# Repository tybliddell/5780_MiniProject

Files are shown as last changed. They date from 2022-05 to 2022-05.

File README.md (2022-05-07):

# ꟼ̷̢̛̭̪̞̑̈́̚Ĩ̴̺͕̞̟́̎͛X̴̨̳̯͖́̈́̉͠Y̷̛̰̲̲̯͆̈́̓Ɔ̷̬̟̲̆̒̄̚ͅA̴̼̻͉̼͋́̿͗M̸͎̘̲̗̊́͘͠ ̶͓̼̜̱̀̔͋͘-̵̡̭̰͓̑̎͐̉ ̶̯͉̟̄̒̀̕͜ꓭ̷͙̦͎̣͑̓̚͝O̷̺̟̪̠̎̋̅͝T̸̳͈͕͖̎̃̅͝

## Explanation

The Pixycam-Bot is a ping pong ball tracking robot that contains a camera that sits on a pan and tilt-controllable assembly to continuously point itself at the ball. The project itself does little more than entertain us, but it could easily be expanded into many different applications including an automatic referee, an auto face-tracking webcam, and more.

## Diagram for project
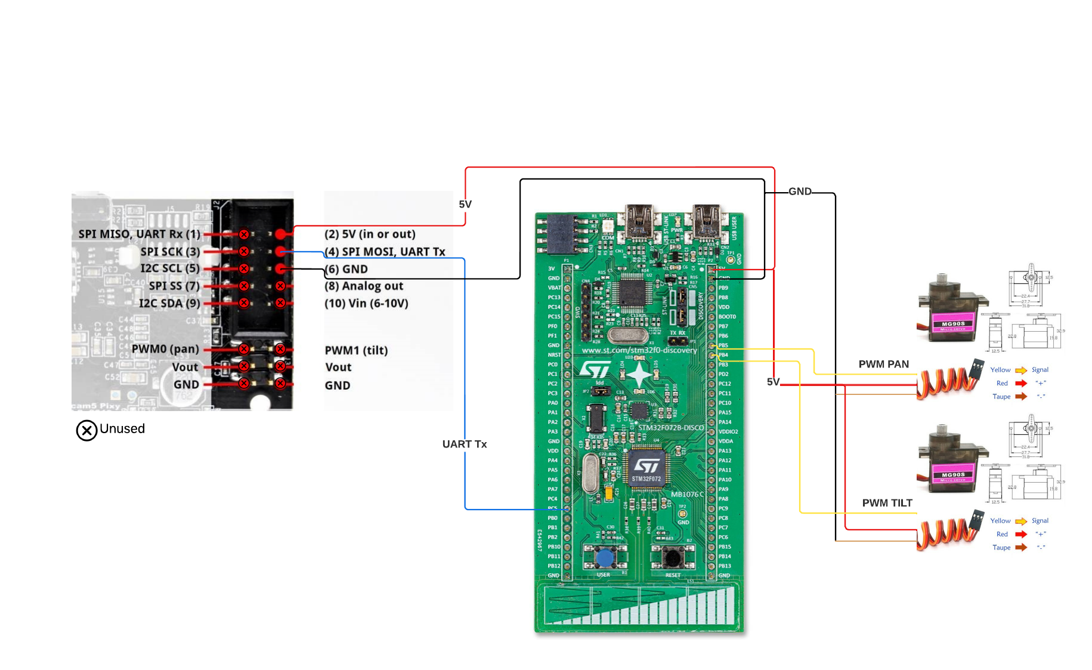
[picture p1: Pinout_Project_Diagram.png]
Pixy Diagram


## Pixy Settings Considerations

We seemed to have a decent amount of success using 115200 for the baud rate of the camera. This is easy to set using the PixyMon software you can obtain at the pixy website [here](https://pixycam.com/downloads-pixy1/). The specifics on how to navigate the software and change these settings can be located on the wiki page [here](https://docs.pixycam.com/wiki/doku.php?id=wiki:v1:porting_guide). 

### Lighting settings

The Pixycam has a lot of settings it holds internally and they can be modified/stored in the memory. There are a few bars that each make some changes to the way the hardware interprets and processes the video stream. Here are the settings for that tuning:

Within the signature tuning tab, you can find the following:
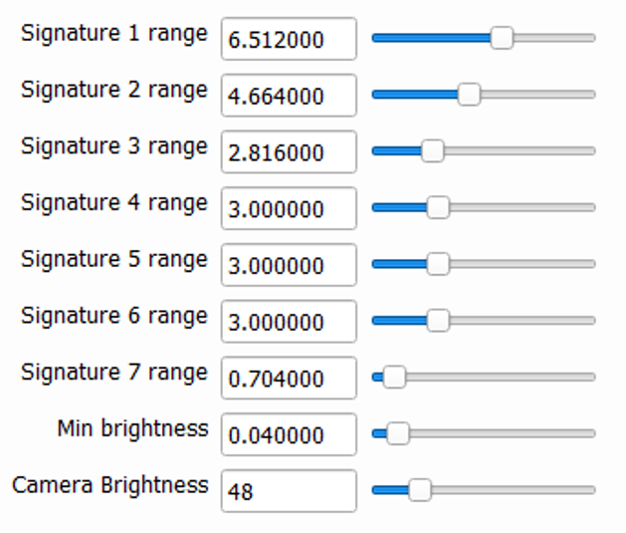
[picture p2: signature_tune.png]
Signature Tuining params


These parameters seem to have different uses for the preprocessing, but have a direct relationship to the amount of post processing that can be done. I was unable to label these with anything useful, so we just sort of played around with the values until we found something that worked well in the lab. Note* This kind of development was mostly due to time, but we quickly realized that the pixy is a camera that can't really be used in a dynamic environment all too well. Using a better camera sensor with beefier post processing techniques would allow for harder, better, faster, and stronger tracking feedback. 

### Capture settings

To capture a single item in frame, we needed to make some mods to the blocks tab. These changes are shown below:

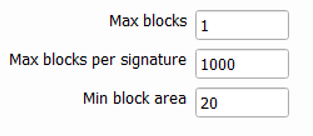
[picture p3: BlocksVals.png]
Changes for Blocks settings


The changes here allow you to capture a specified size, number of captures, and max number of blocks per image captured. Since the ball we were planning to use could be fairly small when farther away, we wanted to make sure the size was still picked up. The 20 min seemed like a decent choice for that value, but we saw some issues with picking up stray signatures around the ball or from reflections in the area. More testing needed to find out what the best way to minimize that would be. 

### Misc settings

The next thing is the baud rate for the UART, and the expert settings are last pieces needed to be configured. Uart settings as well as I2C settings can be seen below and found in the Interface tab, and the Expert tab contains some settings for ...uuhhh experts :) . 

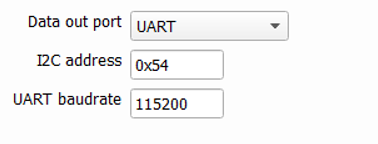
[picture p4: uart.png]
Interface for baud rate


#### Expert stuff

The expert settings are shown below and mostly stay as they are. The LED brightness and the Teaching Threshold are the only ones you likely want to mess with unless you know what you are doing with the others. 

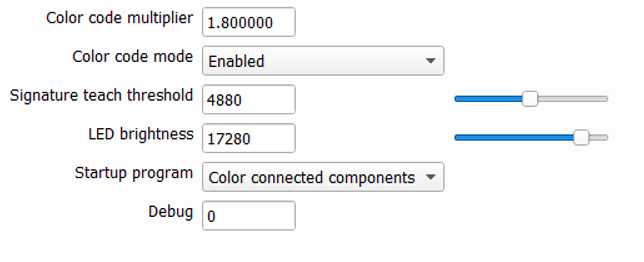
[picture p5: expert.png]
Expert Settings


#### 5780 Mini Project Authors
Tyler Liddell [owns the repo](https://github.com/tybliddell)

Miguel Gomez [Github Page](https://github.com/Mgomez-01)

Rich Baird 😎 [Github Page](https://github.com/richbai90)

Hyrum Saunders [Github Page](https://github.com/hyrum-saunders)

### Project Demonstration and Milestone Explanation
[Watch our demonstration here!](https://youtu.be/rSYqTkc3UDk)

# Thanks for stopping by!

We at the Pixycam-Bot team would like to thank you for making it to the bottom of the readme and going through out stuff! We are glad you could take a moment to rummage through our page to see what we made! As a thank you, we would love for you to take a second to watch this sincere video of us expressing our appreciation.[Enjoy](https://bit.ly/3yhirYQ)

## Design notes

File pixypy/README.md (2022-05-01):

# Pixypy

## A simple pixy emulator written in python

* Communicates over UART
* Simulate motion in x/y plane
* Use different easing functions to simulate realistic motion detection

## TODO

* Document usage
* GUI

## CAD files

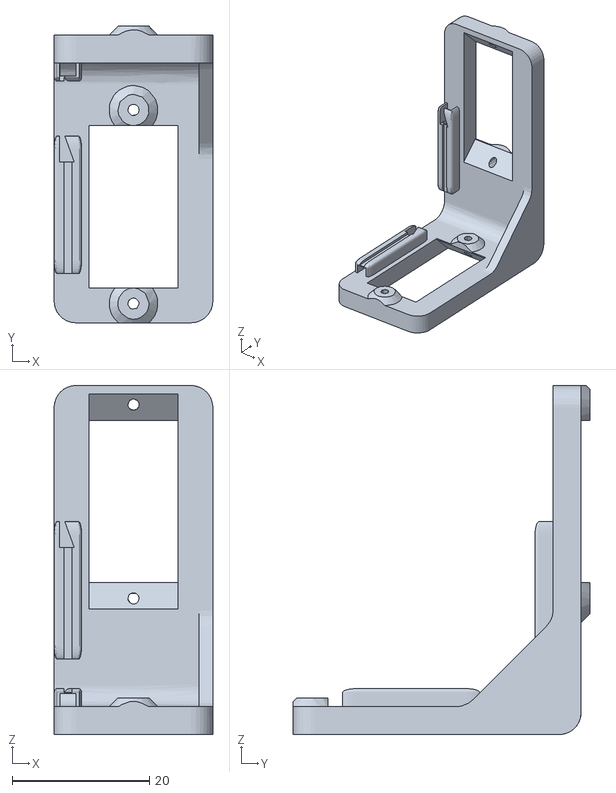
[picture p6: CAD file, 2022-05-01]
print_files/Pan_Tilt_Bracket_V7.stl
23.1 x 43.2 x 50.8

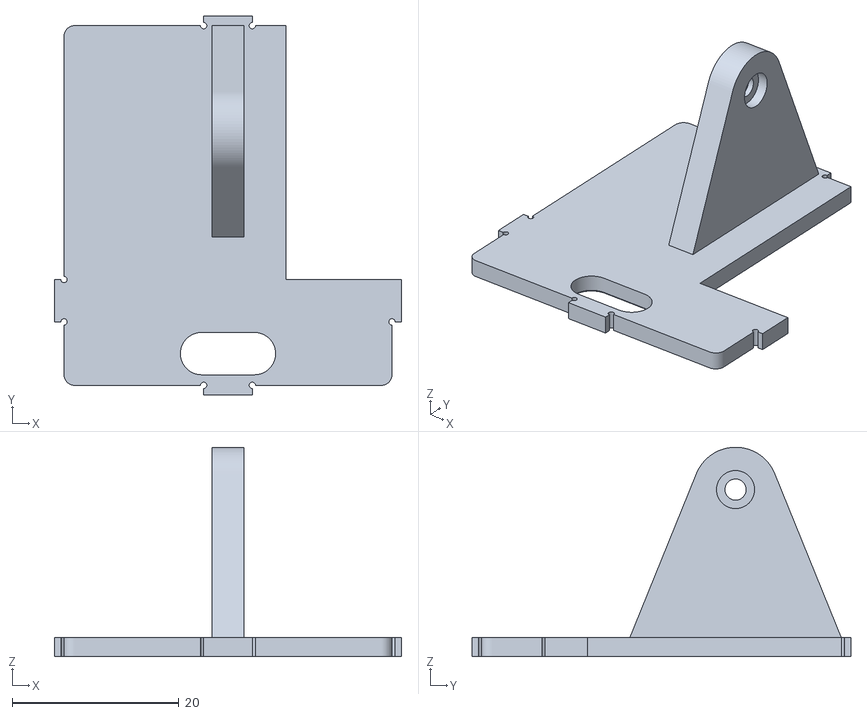
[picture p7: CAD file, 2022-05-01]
print_files/Back_Cover_initial.stl
41.7 x 45.5 x 25.1

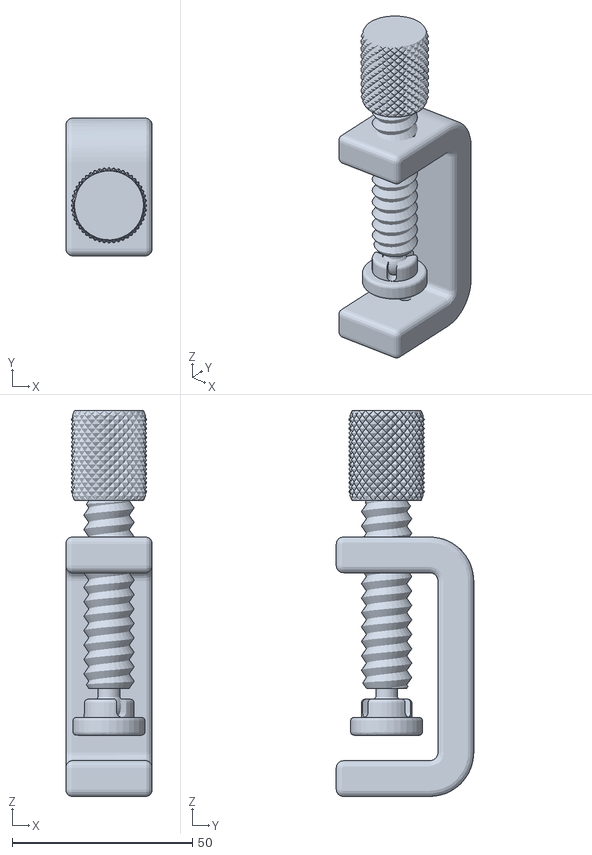
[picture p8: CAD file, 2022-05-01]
print_files/Clamp_Base_V3.stl
23.9 x 38.1 x 107.0

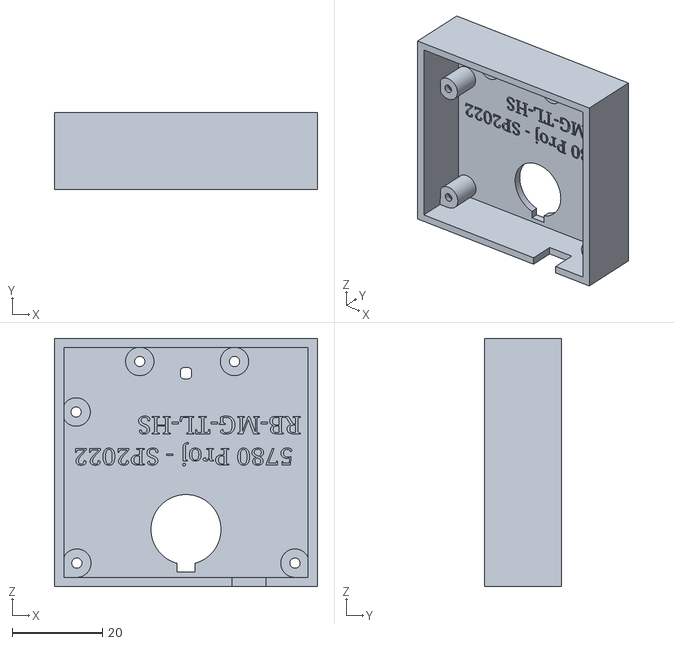
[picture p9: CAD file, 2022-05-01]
print_files/PixyCam_Cover_V22.stl
58.3 x 17.0 x 55.0

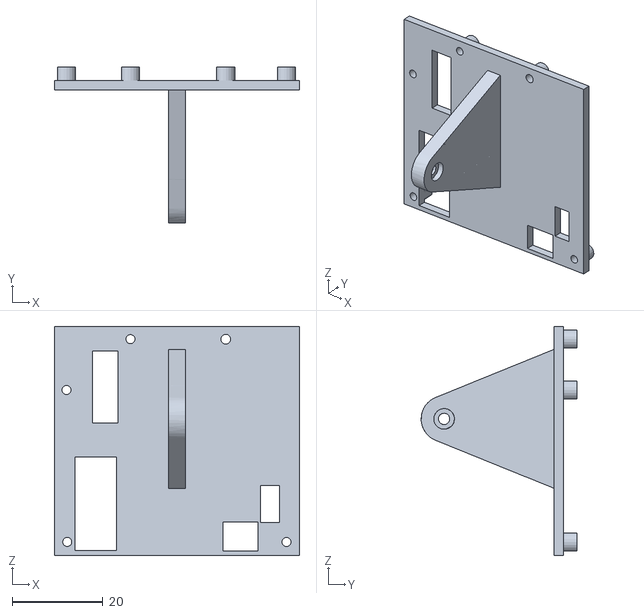
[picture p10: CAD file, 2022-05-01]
print_files/PixyCam_Back_Cover_V20.stl
54.0 x 34.3 x 50.5

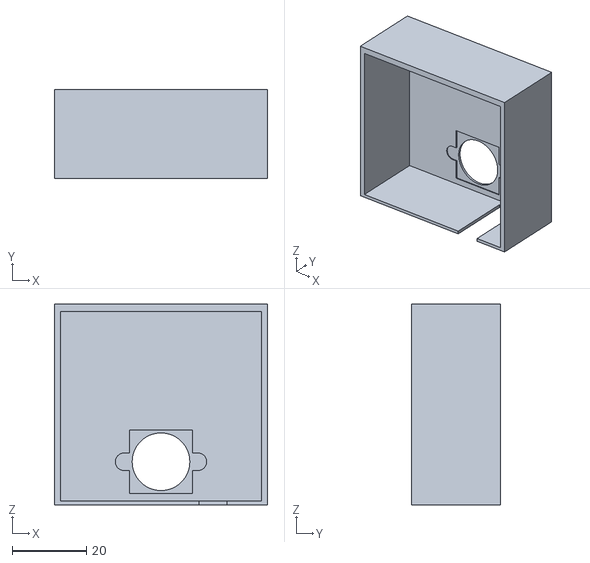
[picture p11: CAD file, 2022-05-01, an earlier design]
print_files/PixyCam_Cover_V4.stl
57.3 x 24.0 x 54.0

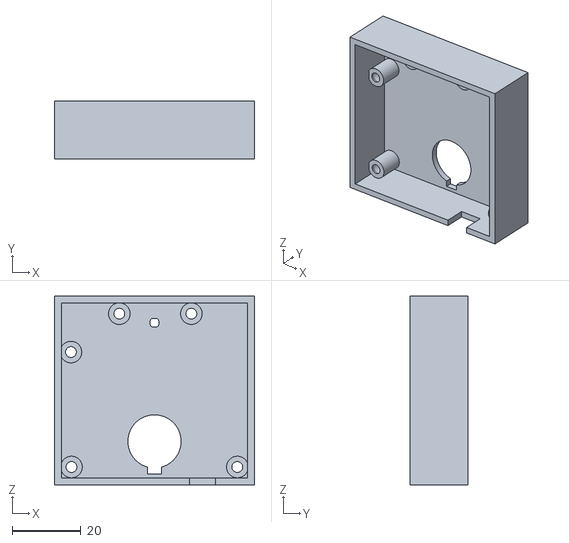
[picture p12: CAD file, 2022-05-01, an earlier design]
print_files/PixyCam_Cover_V11.stl
58.3 x 17.0 x 55.0

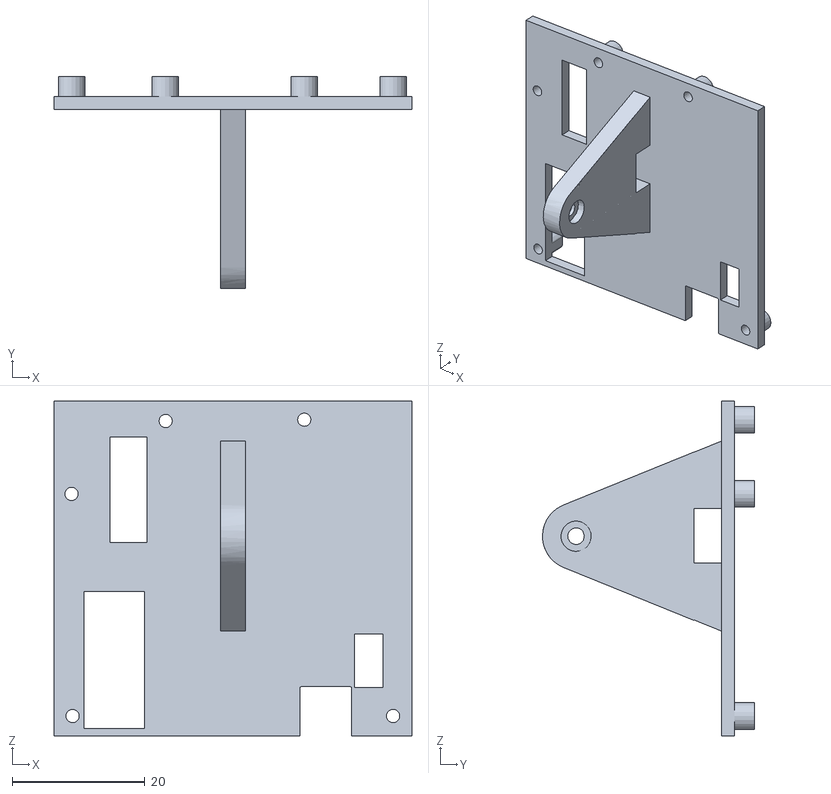
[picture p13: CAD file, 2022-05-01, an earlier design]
print_files/PixyCam_Back_Cover_V9.stl
54.0 x 32.0 x 50.5

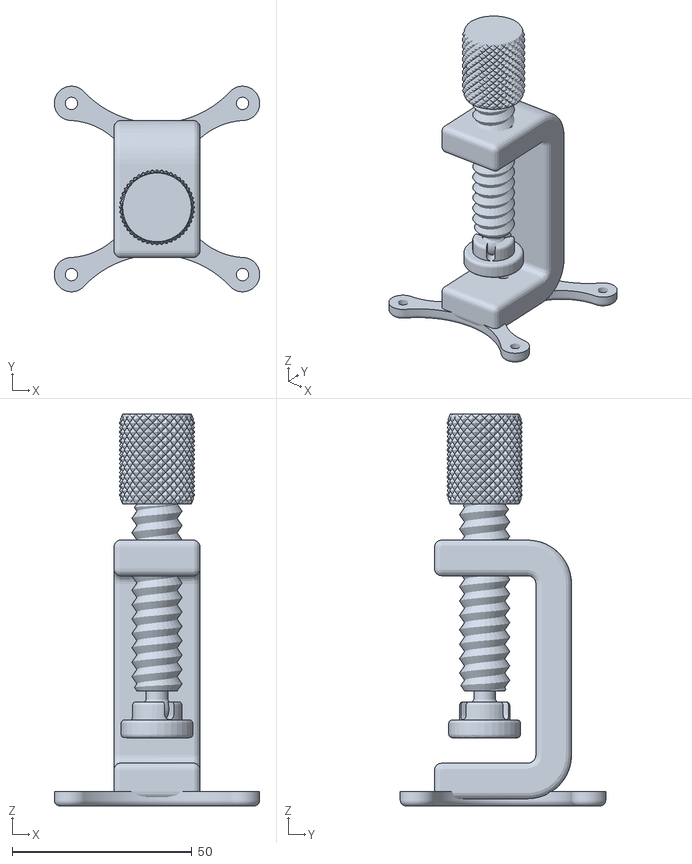
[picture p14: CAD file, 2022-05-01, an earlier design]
print_files/Clamp_Base_V1.stl
57.1 x 57.2 x 109.0

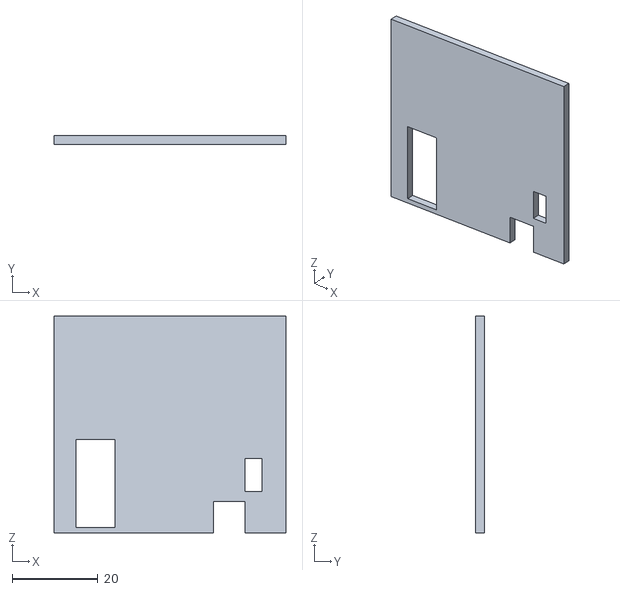
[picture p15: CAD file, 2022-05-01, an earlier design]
print_files/PixyCam_Back_Cover_V1.stl
54.0 x 2.00 x 50.5

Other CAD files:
print_files/Clamp_Base_Final.stl
print_files/gcode_tests/Clamp_diff_vals_screw.3mf
print_files/Pan_Tilt_Bracket_V2.stl
print_files/PixyCam_Cover_V1.stl
print_files/PixyCam_Back_Cover_V10.stl
print_files/PixyCam_Cover_V14.stl
print_files/Pan_Tilt_Bracket_V1.stl
print_files/Pan_Tilt_Bracket_V3.stl
print_files/Pan_Tilt_Bracket_V4.stl
print_files/Pan_Tilt_Bracket_V5.stl
print_files/Pan_Tilt_Bracket_V6.stl
print_files/PixyCam_Back_Cover_V15.stl
print_files/PixyCam_Back_Cover_V2.stl
print_files/PixyCam_Back_Cover_V3.stl
print_files/PixyCam_Back_Cover_V8.stl
print_files/PixyCam_Cover_V15.stl
print_files/PixyCam_Cover_V16.stl
print_files/PixyCam_Cover_V17.stl
print_files/PixyCam_Cover_V18.stl
print_files/PixyCam_Cover_V2.stl

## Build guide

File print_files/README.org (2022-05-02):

* Complete set of printing files needed for the build

** some prints were remixed from parts on Thingiverse.
- pieces remixed were obtained at the following
  [[https://www.thingiverse.com/thing:3180802][Pixy2Stuff]]

Parts did not fit the original PixyCam and the need for modifications arose. All modifications and custom parts made were designed and printed by Miguel Gomez with and Ender 3 3D printer at home. 

** Highlights for the project building process

The total amount of time spent designing, modifying, updating, and revising the 3D prints is not something that was a reqirement for the project, nor was it something that would receive any credit in the project in particular, but I still wanted to update this page to give an overview of the process in case someone would like to take this project and make their own changes/revisions.

In total, there were, on average, 15 different versions of each file that was included in the project that each needed its own care and attention.

*** Housing
The housing of the device in particular had the most amount of revisions as it needed a good fit for the camera, easy outside access to the lens housing of the camera, while also protecting the components on the inside and allowing us to plug in from the rear. The housing was really a single model that I decided to separate into two parts. The rear cover and the shell.

**** shell
The shell needed design changes to allow the camera button on the top to be accessible for reprogramming of the color for tracking, as well as a hold for the lens and the LED that indicated whether or not something was located. These modifications were completed by myself (Miguel Gomez) as I took measurements of the board and created a custom model in fusion 360 that I used as the starting point.

From there, revisions to the model were made as I dialed in the printer settings necessary to minimize squish at the floor, shrinkage of the part as it cooled, and modified the amount of infill for the rigidity/structure of the housing. Part of that process is shown in the included images directory and the stl files that are seen above.  

**** rear cover
The rear cover was a bit trickier. In addition to the squish at the floor and shrinkage of the part as it cools, it required a change in orientation for the print after adding in the pieces for the screws to attach to. These changes allowed for the screws to make good contact with the rear cover through the housing holes, and allow for a good adhesion of the mounting arm for the servo motor. The design was modified to shift the arm further back after it was found to interfere with the mobility of the tilting given the connected wires on the back of the camera. Adding in the extra space allowed for a fluid movement that did not cause any pinching in the wires, minimizing the stresses on the wires over time as the assembly moved around.

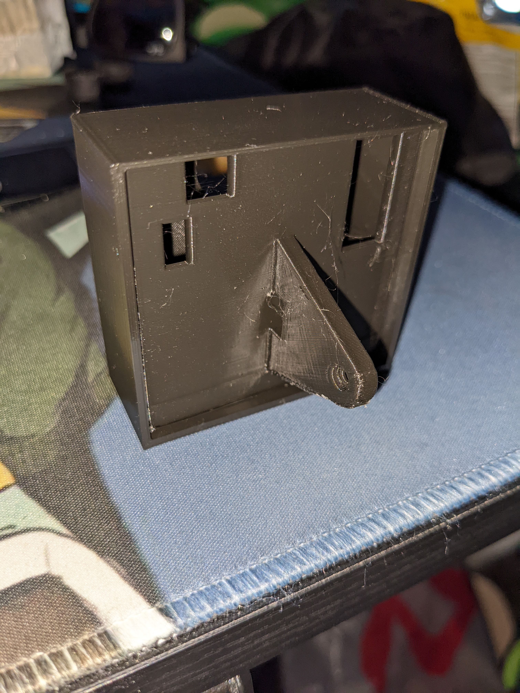
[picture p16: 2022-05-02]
print_files/images/Housing_and_cover.jpg

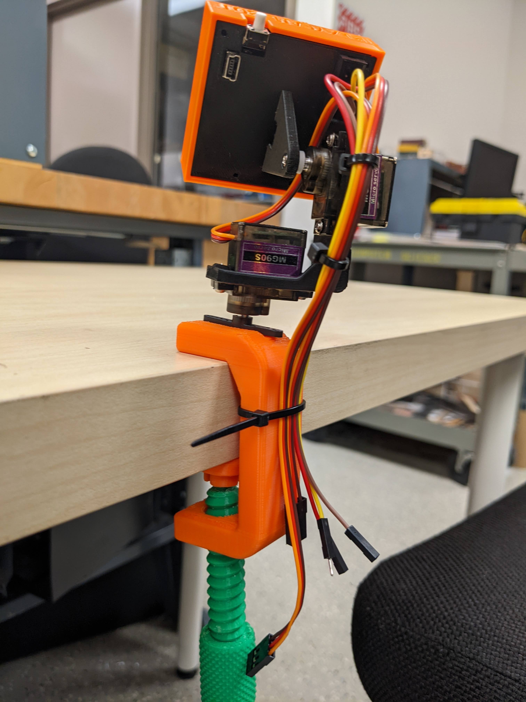
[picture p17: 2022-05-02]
print_files/images/cables_management.jpg

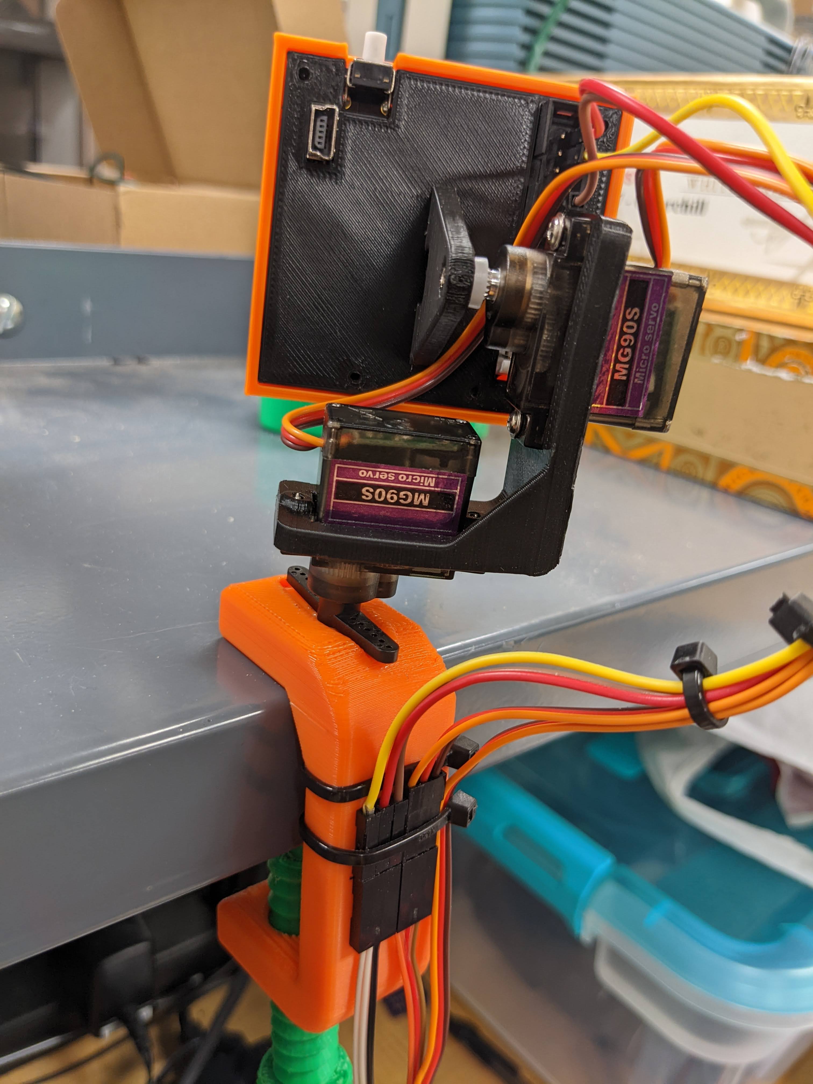
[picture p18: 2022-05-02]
print_files/images/Complete_cables_tied.jpg

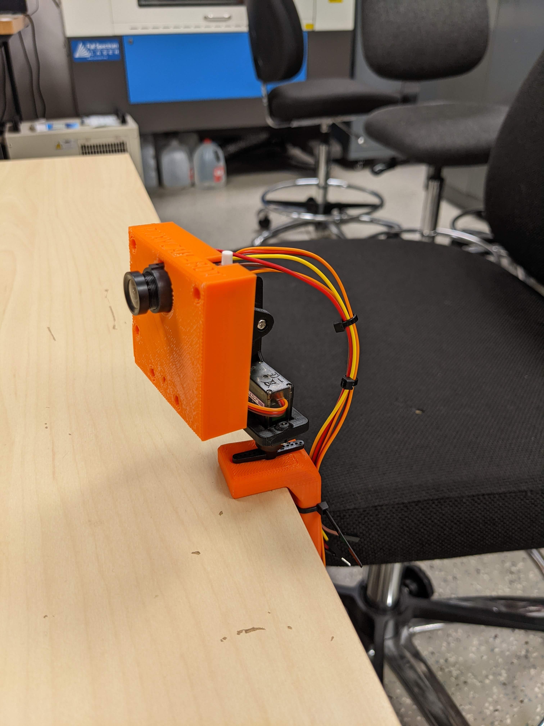
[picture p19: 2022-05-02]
print_files/images/Nearly_complete.jpg

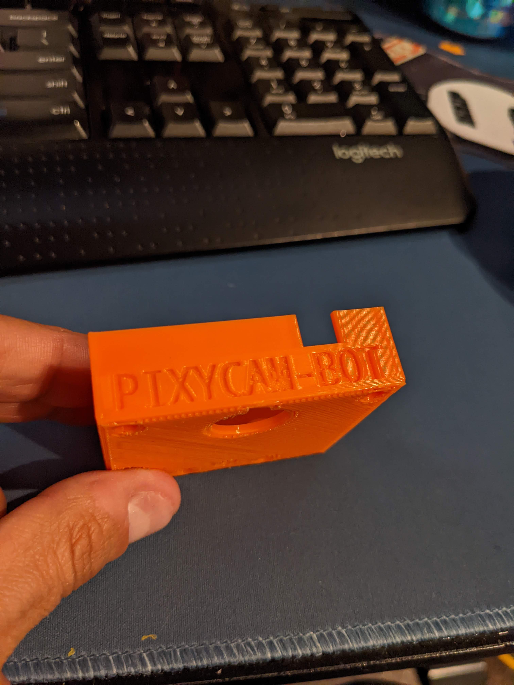
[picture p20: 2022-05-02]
print_files/images/Naming_the_bot.jpg

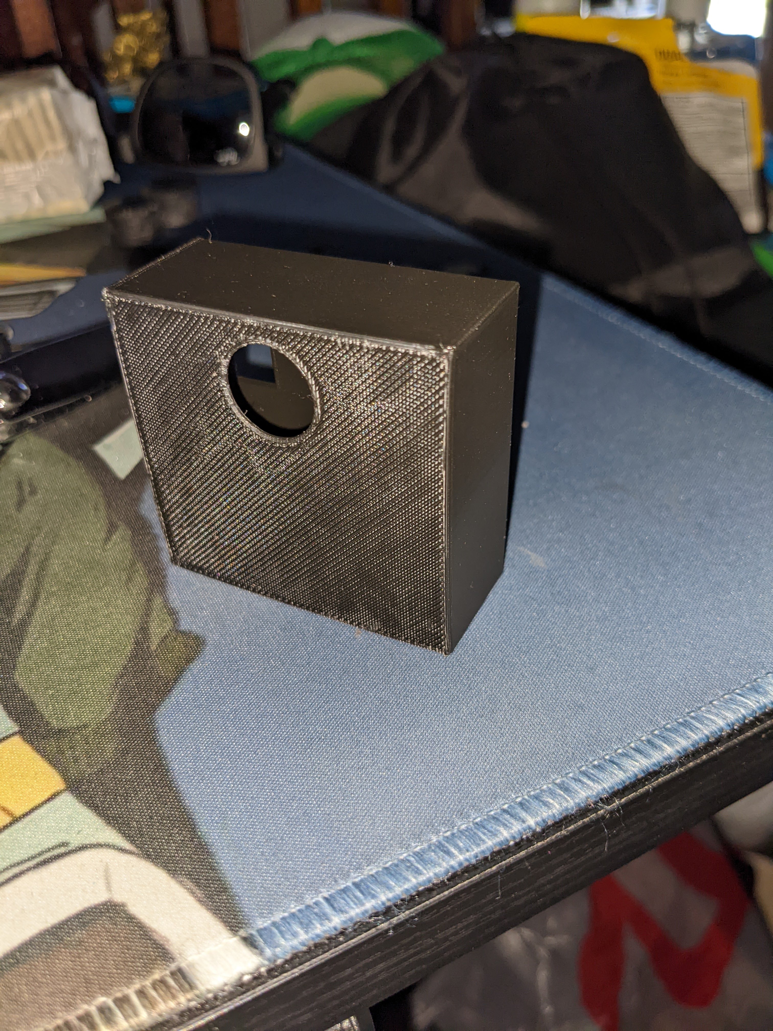
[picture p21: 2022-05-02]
print_files/images/Housing1_front.jpg

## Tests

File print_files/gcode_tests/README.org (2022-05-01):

* Gcode files for 3D printer.

All settings specified here under the top level comments in each file show the limits of printer. Take special care if you try to run them as they have custom startoff code, bed size settings, and assume a bed leveling system is installed (BLTouch) and functions!

*TAKE NOTE : I do not assume any responsibility for someone running gcode they found online...

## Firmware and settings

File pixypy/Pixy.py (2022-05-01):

import serial
import easing_functions
import numpy as np


class Pixy:
    '''
    A Pixycam Emulator class. Communicates over UART to simulate a working Pixycam
    '''

    def __init__(self):
        self.preamble =bytearray([0xAA, 0x55, 0xFF, 0xFF, 0xFF, 0xFF])
        self.suffix = bytearray([0x0A, 0x00, 0x0A, 0x0A])
        self.x: float = 0
        self.y: float = 0
        self.port = ''
        self.easing_fn = 'CubicEaseIn'
        self.steps = 10
        self.ser = None

    def _validate_coords(self, v, is_x):
        '''
        Clamp x and y to valid coordinate
        '''
        v = int(v)
        if is_x and (v > 312):
            v = 312
        elif is_x and (v < 0):
            v = 0
        elif not is_x and (v > 205):
            v = 205
        elif not is_x and (v < 0):
            v = 0

        return v

    def _get_easing_fn(self, function):

        try:

            if hasattr(easing_functions, function) and callable(fn := getattr(easing_functions, function)):
                return fn
        except Exception as e:
            print(e)

        return None

    def move_left(self, amt, steps=0, mode=None):
        '''
        Emulate the response generated by an object moving left by amt
        '''
        amt = int(amt)
        if not mode:
            mode = self.easing_fn

        if steps == 0:
            steps = self.default_steps
        easing = self._get_easing_fn(mode)
        step = easing(start=self.x, end=self._validate_coords(
            self.x - amt, True), duration=steps)
        self.send_command(step)

    def move_right(self, amt, steps=0, mode=None):
        '''
        Emulate the response generated by an object moving right by amt
        '''
        amt = int(amt)
        if not mode:
            mode = self.easing_fn

        if steps == 0:
            steps = self.default_steps
        easing = self._get_easing_fn(mode)
        step = easing(start=self.x, end=self._validate_coords(
            self.x + amt, True), duration=steps)
        self.send_command(step)

    def move_up(self, amt, steps=0, mode=None):
        '''
        Emulate the response generated by an object moving up by amt
        '''
        if not mode:
            mode = self.easing_fn

        if steps == 0:
            steps = self.default_steps
        easing = self._get_easing_fn(mode)
        step = easing(start=self.y, end=self._validate_coords(
            self.y - amt, False), duration=steps)

    def move_down(self, amt, steps=0, mode=None):
        '''
        emulate the response generated by an object moving down by amt
        '''
        amt = int(amt)
        if not mode:
            mode = self.easing_fn

        if steps == 0:
            steps = self.default_steps
        easing = self._get_easing_fn(mode)
        step = easing(start=self.y, end=self._validate_coords(
            self.y + amt, False), duration=steps)

    def go_to(self, x, y, steps=0, mode=None):
        '''
        Emulate the response generated by an object moving to the specified location
        '''
        if not mode:
            mode = self.easing_fn

        if steps == 0:
            steps = self.default_steps
        easing = self._get_easing_fn(mode)
        step_x = easing(
            start=self.x, end=self._validate_coords(x, True), duration=steps)
        step_y = easing(
            start=self.x, end=self._validate_coords(y, False), duration=steps)

    def begin(self, options):
        self.x = self._validate_coords(options['coords'][0], True)
        self.y = self._validate_coords(options['coords'][1], False)
        self.port = options['port']
        self.easing_fn = options['easing_fn']
        self.default_steps = options['steps']
        self.baud_rate = options['baud_rate']
        try:
            self.ser = serial.Serial(port=self.port, baudrate=self.baud_rate)
        except OSError:
            self.ser = serial.Serial(port=self.port, baudrate=self.baud_rate,  rtscts=True, dsrdtr=True)

    def send_command(self, x_steps, y_steps):
        if not self.ser.is_open:
            self.ser.open()
        for step in range(steps.duration + 1):
            data = self.preamble
            data.append(np.int16(np.floor(x_steps(step))) & 0xFF)
            data.append(np.int16(np.floor(x_steps(step))) & 0xFF00)
            data.append(np.int16(np.floor(y_steps(step))) & 0xFF)
            data.append(np.int16(np.floor(y_steps(step))) & 0xFF00)
            data.append(self.suffix)
            self.ser.write(data)

    def send_command(self, steps, is_x=True):
        if not self.ser.is_open:
            self.ser.open()
        for step in range(steps.duration + 1):
            data = self.preamble
            if is_x:
                data.append(np.int16(np.floor(steps(step))) & 0xFF)
                data.append(np.int16(np.floor(steps(step))) & 0xFF00)
                data.append(np.int16(np.floor(self.y)) & 0xFF)
                data.append(np.int16(np.floor(self.y)) & 0xFF00)
            else:
                data.append(np.int16(np.floor(self.x)) & 0xFF)
                data.append(np.int16(np.floor(self.x)) & 0xFF00)
                data.append(np.int16(np.floor(steps(step))) & 0xFF)
                data.append(np.int16(steps(np.floor(step))) & 0xFF00)
            data.append(self.suffix)
            self.ser.write(data)


if __name__ == '__main__':
    print("Pixy is a library and should only be used as an import!")
    exit(1)

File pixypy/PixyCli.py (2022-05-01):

from .Pixy import Pixy
import click, sys, re
from serial.tools import list_ports

pixy = Pixy()

@click.group(invoke_without_command=True)
@click.pass_context
def move(ctx):
    if ctx.invoked_subcommand is None:
        if(ctx.obj and ctx.obj['cmd_pieces'] and len(ctx.obj['cmd_pieces'])):
            cmd = globals()[ctx.obj['cmd_pieces'].pop(0)]
            params = {}
            for idx, arg in enumerate(cmd.params):
                params[arg.name] = ctx.obj['cmd_pieces'][idx]
            ctx.invoke(cmd, **params)
        else:
            move('help')


@click.command()
def tty():
    ports = sorted(list_ports.comports(include_links=True))
    opts = {}
    if(len(ports)):
        click.echo(
            "Please select the port you wish to send pixy data over from the list below"
        )
        click.echo(f"{'':<5} {'Port':^10} {'Description':^30} {'HWID':^10}")
        click.echo('-----------------------------------------------------')
        for idx, [port, desc, hwid] in enumerate(ports):
            click.echo(
                f"{f'({idx})':<5}{port:^5} {desc:^20} {f'[{hwid}]':^21}")

        opts['port'] = click.prompt(
            "Port", 0, value_proc=(lambda port: ports[int(port)][0]))
        opts['coords'] = click.prompt("Starting Coordinates x,y", '0,0', value_proc=(
            lambda xy: [int(xy.split(',')[0]), int(xy.split(',')[1])]))
        opts['steps'] = click.prompt('Default Number of Steps Per Transition',10)
        opts['easing_fn'] = click.prompt('Default Easing Function', 'CubicEaseIn')
        opts['baud_rate'] = click.prompt('Baud Rate:', 9600)
        pixy.begin(opts)
        await_command()

    else:
        click.echo("There are no com ports available on your system!")
        exit(1)

def await_command():
    cmd : string = click.prompt("Enter a command")
    pieces = list(filter((lambda s: s != '' and not re.search("^\\s+$", s)), cmd.split(' ')))
    group = pieces.pop(0)
    obj = {"cmd_pieces": pieces, "group": group}
    move(obj=obj)
        
    
def is_string(O):
    return hasattr(O, 'upper') and callable(O.upper)

@move.command()
@click.argument('amt')
def left(amt):
    '''Send the pixy commands corresponding to moving the tracked object left by the given amount'''
    pixy.move_left(amt)

@move.command()
@click.argument('amt')
def right(amt):
    '''Send the pixy commands corresponding to moving the tracked object right by the given amount'''
    pixy.move_right(amt)

@move.command()
@click.argument('amt')
def up(amt):
    '''Send the pixy commands corresponding to moving the tracked object up by the given amount'''
    pixy.move_up(amt)

@move.command()
@click.argument('amt')
def down(amt):
    '''Send the pixy commands corresponding to moving the tracked object down by the given amount'''
    pixy(amt)

@move.command()
@click.argument('x')
@click.argument('y')
def to(x, y):
    '''Send the pixy commands corresponding to moving the tracked object to the destination via a straight line'''
    pixy.go_to(x, y)

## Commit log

2022-03-24 Added async RX over UART from pixy
2022-03-30 Add servo controll
2022-03-30 Integrate servo control into 5780 mini project folder and delete servo control folder
2022-04-30 Smooth out movement for new servos
2022-05-01 The complete collection of files for the prints made. Was planning on leaving these out, but lots of work went into completing these as well as time printing and modifying the stl files to get the fi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
    [Back_Cover_initial.stl, Clamp_Base_Final.stl, Clamp_Base_V1.stl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]
2022-05-01 Readme for prints
2022-05-01 Adding in various print gcode files to show a bit of the process that these go through. Settings must be dialed in for parts as they are developed and it is not as simple as creating the part then hi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
    [Clamp_diff_vals_screw.3mf]
2022-05-02 Fixed accidental tab over that led to text block being quoted as code instead of markdown.
2022-05-02 adding in some photos of the prints and build process as it progressed
2022-05-02 added more about prints to readme and will also be adding in images to show the design choices
2022-05-07 Added info for the Baud Rate and where to set it for the camera.
2022-05-07 added some info on the expert tab as well as the uart stuff
2022-05-07 adding images for the uart and expert tabs
2022-05-07 added in files for the images of uart and expert information.
